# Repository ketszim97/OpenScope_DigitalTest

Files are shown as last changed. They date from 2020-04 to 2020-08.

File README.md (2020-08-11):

# OpenScope_DigitalTest
Digital Test board for an Open Source FPGA Oscilloscope

- Lattice MachX02 FPGA
- AD9481 250Msps ADC
- 128Mb Hyper RAM

Fusion Render 1
Fusion Render 2

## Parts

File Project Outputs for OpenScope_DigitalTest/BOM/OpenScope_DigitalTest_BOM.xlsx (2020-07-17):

Comment | Description | Designator | Footprint | LibRef | Quantity | Value | MANF | MFN_PN | Supplier 1 | Supplier Part Number 1 | Supplier 2 | Supplier Part Number 2 | LCSC Part Number
C0603 1uF 25V X7R | CAP CER 1UF 25V X7R 0603 | C3, C4 | C0603-IPC | C0603 1uF 25V X7R | 2 | 1uF | TDK |  | Digi-Key | 445-173615-1-ND |  |  | CL10A105KA8NNNC (https://lcsc.com/product-detail/Multilayer-Ceramic-Capacitors-MLCC-SMD-SMT_SAMSUNG_CL10A105KA8NNNC_1uF-105-10-25V_C5673.html)
C0603 100nF 25V X7R | Chip Capacitor, 0603, 100nF, 25V, X7R | C5, C6, C8, C9, C10, C11, C13, C14, C17, C19, C21, C27, C28, C29, C30, C31, C32, C33, C34, C35, C38, C41, C43, C44, C45, C46, C47, C48, C50, C52, C53, C54, C55, C58 | C0603-HIGH-DENSITY | C0603 100nF 25V X7R | 34 | 100nF | Murata |  | Digi-Key | 490-1524-1-ND |  |  | GRM188F51E104ZA01D (https://lcsc.com/product-detail/Multilayer-Ceramic-Capacitors-MLCC-SMD-SMT_muRata_GRM188F51E104ZA01D_100nF-104-80-20-25V_C86002.html)
GRM155R71H104KE14D | Chip Capacitor, 0402, 0.10uF, 50V, X7R | C7, C15, C18, C22, C23, C37, C39 | C0402-HIGH-DENSITY | C0402 0.1uF 50V X7R | 7 | 0.1uF | Murata |  | Digi-Key | 490-10700-1-ND |  |  | CC0402KRX7R8BB104 (https://lcsc.com/product-detail/Multilayer-Ceramic-Capacitors-MLCC-SMD-SMT_100nF-104-10-25V_C105883.html)
C0603 10uF 10V X5R | Chip Capacitor, 0603, 10uF, 10V, X5R | C1, C2, C12, C20, C24, C25, C26, C36, C51 | C0603-HIGH-DENSITY | C0603 10uF 10V X5R | 9 | 10uF | Murata |  | Digi-Key | 490-10474-1-ND |  |  | GRM188R61A106ME69D (https://lcsc.com/product-detail/Multilayer-Ceramic-Capacitors-MLCC-SMD-SMT_Murata-Electronics_GRM188R61A106ME69D_Murata-Electronics-GRM188R61A106ME69D_C90053.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)
C0402 10uF 10V | Chip Capacitor, 0402, 10uF, 10V, X5R | C16, C40 | C0402-HIGH-DENSITY | C0402 10uF 10V | 2 | 10uF | Samsung |  | Digi-Key | 1276-1450-2-ND |  |  | GRM155R61A106ME44D (https://lcsc.com/product-detail/Multilayer-Ceramic-Capacitors-MLCC-SMD-SMT_muRata_GRM155R61A106ME44D_10uF-106-20-10V_C77000.html)
C0603 4.7uF 6.3V X5R | Chip Capacitor, 0603, 4.7uF, 10V, X5R | C42, C49 | C0603-HIGH-DENSITY | C0402 4.7uF 6.3V X5R | 2 | 4.7uF | Samsung |  | Digi-Key | 1276-1907-1-ND |  |  | CL05A475MQ5NRNC (https://lcsc.com/product-detail/Others_Samsung-Electro-Mechanics_CL05A475MQ5NRNC_Samsung-Electro-Mechanics-CL05A475MQ5NRNC_C307423.html)
C0603 18pF 50V C0G_1 | Chip Capacitor, 0603, 18pF, 25V, C0G | C56, C57 | C0603-HIGH-DENSITY | C0402 18pF 50V C0G_1 | 2 | 18pF | KEMET |  | Digi-Key | 399-9019-1-ND |  |  | 0402CG180G500NT (https://lcsc.com/product-detail/Multilayer-Ceramic-Capacitors-MLCC-SMD-SMT_FH-Guangdong-Fenghua-Advanced-Tech-0402CG180G500NT_C182481.html)
LED0, LED1, LED2, LED3, LED4, LED5, LED6, LED7 | LED GREEN CLEAR 0603 SMD | D1, D2, D3, D4, D5, D6, D7, D8 | LED0603-IPC | LED 0603 Green | 8 | Green | Wurth Electronics |  | Digi-Key | 732-4971-1-ND |  |  | LTST-C193KGKT-5A (https://lcsc.com/product-detail/Light-Emitting-Diodes-LED_SMD-green_C125102.html)
5V, 3.3V PWR, 1.8V | LED RED CLEAR 0603 SMD | D9, D10, D11 | LED0603-IPC | LED 0603 Red | 3 | Red | Wurth Electronics |  | Digi-Key | 732-4979-1-ND |  |  | LTST-C193KRKT-5A (https://lcsc.com/product-detail/Light-Emitting-Diodes-LED_SMD-red_C157741.html)
VIN-, VIN+ | SMA Connector | J6, J7 | SMA_CONN | SMA | 2 |  | TE Connectivity |  | Digi-Key | A97594-ND |  |  | KH-SMA-K513-G (https://lcsc.com/product-detail/RF-Connectors-Coaxial-Connectors_Shenzhen-Kinghelm-Elec-KH-SMA-K513-G_C411575.html)
Ferrite Bead | 600 Ohms @ 100MHz 1 Ferrite Bead 0603 (1608 Metric) 500mA 380mOhm | L1, L2, L3 | L0603 | FB 0603 600R @ 100MHz | 3 | 600R 100MHz | Murata |  | Digi-Key | 490-1014-1-ND |  |  | CBG160808U601T (https://lcsc.com/product-detail/Ferrite-Beads_FH-Guangdong-Fenghua-Advanced-Tech-CBG160808U601T_C73326.html)
R0402 100R 1% | Chip Resistor, 0402, 100 ohms, 1%, 1/16 W | R1 | R0402-HIGH-DENSITY | R0402 100R 1% | 1 | 100 | Yageo |  | Digi-Key | 311-100LRCT-ND |  |  | ARG03DTC1000 (https://lcsc.com/product-detail/Others_Viking-Tech-ARG03DTC1000_C311907.html)
R0603 1K 1% | RES SMD 1K OHM 1% 1/10W 0603 | R2, R3, R4, R5, R6, R7, R8, R9 | R0603-IPC | R0603 1K 1% | 8 | 1k | Stackpole Electronics |  | Digi-Key | RMCF0603FG1K00CT-ND |  |  | 0603WAF1001T5E (https://lcsc.com/product-detail/Chip-Resistor-Surface-Mount_UNI-ROYAL-Uniroyal-Elec-0603WAF1001T5E_C21190.html)
R0603 4.99K 0.1% | RES SMD 4.99KOHM 0.1% 1/10W 0603 | R10, R11, R12 | R0603-HIGH-DENSITY | R0603 4.99K 0.1% | 3 | 4.99k | Panasonic |  | Digi-Key | P4.99KDBCT-ND |  |  | WR06X4991FTL (https://lcsc.com/product-detail/Chip-Resistor-Surface-Mount_Walsin-Tech-Corp-WR06X4991FTL_C163916.html)
R0603 2.2K 1% | RES SMD 2.2K OHM 1% 1/10W 0603 | R13, R14, R19 | R0603-IPC | R0603 2.2K 1% | 3 | 2.2k | Stackpole Electronics |  | Digi-Key | RMCF0603FT2K20CT-ND |  |  | 0603WAF2201T5E (https://lcsc.com/product-detail/Chip-Resistor-Surface-Mount_UNI-ROYAL-Uniroyal-Elec-0603WAF2201T5E_C4190.html)
R0603 12k 1% | RES 12K OHM 1% 1/10W 0603 | R15 | R0603-HIGH-DENSITY | R0603 12k 1% | 1 | 12k | Vishay |  | Digi-Key | 541-12.0KHCT-ND |  |  | 0603WAF1202T5E (https://lcsc.com/product-detail/Chip-Resistor-Surface-Mount_UNI-ROYAL-Uniroyal-Elec-0603WAF1202T5E_C22790.html)
R0603 10K 1% | RES SMD 10K OHM 1% 1/10W 0603 | R16, R17, R18, R23, R24 | R0603-IPC | R0603 10K 1% | 5 | 10k | Stackpole Electronics |  | Digi-Key | RMCF0603FT10K0CT-ND |  |  | MCT06030C1002FP500 (https://lcsc.com/product-detail/Others_Vishay-Intertech_MCT06030C1002FP500_Vishay-Intertech-MCT06030C1002FP500_C161803.html)
R0603 100 1% | RES SMD 100 OHM 1% 1/4W 0603 | R20, R21 | R0603-IPC | R0603 100 1% | 2 | 100 | Vishay Dale |  | Digi-Key | 541-3244-1-ND |  |  | WR06X101JTL (https://lcsc.com/product-detail/Chip-Resistor-Surface-Mount_Walsin-Tech-Corp-WR06X101JTL_C163845.html)
FPGA_PROGRAM_N, SW1, SW2 | SWITCH TACTILE SPST-NO 0.05A 12V | S1, S2, S3 | TL3342F260QG | SWITCH TACTILE SPST | 3 |  | E-Switch | TL3342F260QG | Digi-Key | EG5470CT-ND |  |  | TS5215A 160gf (https://lcsc.com/product-detail/Tactile-Switches_SHOU-HAN-TS5215A-160gf_C412369.html)
LD1086D2M33TR | 1.5A, Low Drop Positive Voltage Regulator, 3.3V, 4-Pin D2PAK/A, Tape and Reel | U1 | D2PAK_A_L | CMP-0244-00505-1 | 1 |  | STMicroelectronics | LD1086D2M33TR | Digi-Key | 497-1223-1-ND | Mouser | 511-LD1086D2M33-TR | C262918 (https://lcsc.com/product-detail/Others_STMicroelectronics_LD1086D2M33TR_STMicroelectronics-LD1086D2M33TR_C262918.html)
MCP1703T-1802E/CB | 250 mA, 16V, Low Quiescent Current LDO Regulator, 3-Pin SOT-23A, Extended Temperature, Tape and Reel | U2 | SOT-23A-CB3_N | CMP-0136-00766-1 | 1 |  | Microchip | MCP1703T-1802E/CB | Digi-Key | MCP1703T-1802E/CBCT-ND | Mouser | 579-MCP1703T-1802ECB
LCMXO2-4000 |  | U3 | TQFP144 | MachXO2-4000-TG144 | 1 |  | Lattice Semiconductor Corporation | LCMXO2-4000HC-4TG144C | DigiKey | 220-1460-ND | Mouser | 842-XO24000HC4TG144C
AD9481BSUZ-250 | Single ADC Pipelined 250Msps 8-bit Parallel/LVDS 44-Pin TQFP Tray | U4 | QFP80P1200X1200X120-44N | AD9481BSUZ-250 | 1 |  | Analog Devices Inc. | AD9481BSUZ-250 | DigiKey | AD9481BSUZ-250-ND | Mouser | 584-AD9481BSUZ-250
S70KS128 | PSRAM (Pseudo SRAM) Memory IC 128Mb (16M x 8) Parallel 166MHz 36ns 24-FBGA (6x8) | U5 | Cypress-VAA024 | S70KS | 1 |  | Cypress | S70KS1281DPBHV020 | Digi-Key | 2015-S70KS1281DPBHV020-ND | Mouser | 727-S70KS1281DPBHV02
FT2232HL-Reel | Dual High Speed USB To Multipurpose UART/FIFO IC, 64-pin LQFP, Tape and Reel | U6 | LQFP-64_M | CMP-0078-00023-3 | 1 |  | FTDI | FT2232HL-Reel | Digi-Key | 768-1024-1-ND | Mouser | 895-FT2232HL | C27882 (https://lcsc.com/product-detail/USB-ICs_FTDI-Future-Designs_FT2232HL-REEL_FTDI-Future-Designs-FT2232HL-REEL_C27882.html)
EEPROM 2Kb SPI | EEPROM Memory IC 2Kb (256 x 8, 128 x 16) SPI 3MHz 8-SOIC | U8 | SOIC127P600X175-8N | 93LC56C-I/SN | 1 |  | Microchip | 93LC56C-I/SN | Digi-Key | 93LC56C-I/SN-ND | Mouser | 579-93LC56C-I/SN
USB micro-B | CONN RCPT USB TYPE B 3A | USB1 | USB-MicroB | USB micro-B | 1 |  | Amphenol ICC | 629105150521 | Digi-Key | 609-4616-1-ND |  |  | C40955 (https://lcsc.com/product-detail/USB-Connectors_Jing-Extension-of-the-Electronic-Co-Jing-Extension-of-the-Electronic-Co-micro-5PBoard5-9No-column-plus-welding-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)
ABM8G-12.000MHZ-18-D2Y-T | Ultra Miniature Ceramic Glass Sealed SMD Cryastal, 12 MHz, 18 pF, +/- 20 ppm, -40 to 85 degC, 4-Pin SMD, RoHS, Tape and Reel |  | ABRACON_ABM8G_V | CMP-2000-05039-1 | 1 |  | Abracon | ABM8G-12.000MHZ-18-D2Y-T | Digi-Key | 535-10261-1-ND | Mouser | 815-ABM8G-12-18D2Y | C276421 (https://lcsc.com/product-detail/SMD-Crystal-Resonators_Abracon-LLC_ABM8G-12-000MHZ-B4Y-T_Abracon-LLC-ABM8G-12-000MHZ-B4Y-T_C276421.html)
EPSON 250MHz XTAL | 250MHz XO (Standard) LVDS Oscillator 2.5V ~ 3.3V Enable/Disable 6-SMD, No Lead | Y1 | EPSON SG5032 | SG5032VAN 250.000000M-KEGA3 | 1 |  | Epson | SG5032VAN 250.000000M-KEGA3 | Digi-Key | SER3984CT-ND | Mouser | 732-5032V250.00KEGA3
Renesas 125MHz OSC | 125MHz XO (Standard) HCMOS Oscillator 3.3V Enable/Disable 6-SMD, No Lead | Y2 | EPSON SG5032 | XLH535125.000000I | 1 |  | Renesas Electronics America Inc | XLH535125.000000I | Digi-Key | 800-4278-ND | Mouser | 972-LH535125.000000I

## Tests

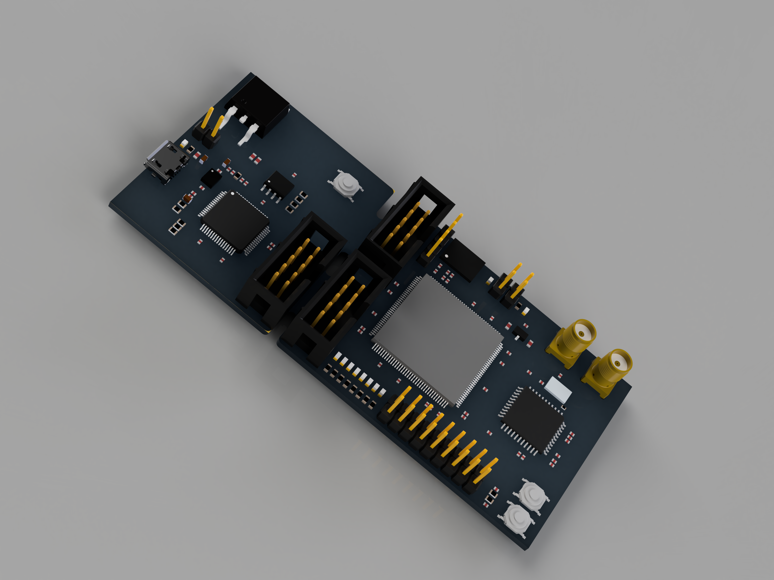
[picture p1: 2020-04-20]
Renders/DigitalTest_2020-Apr-18_06-35-39AM-000_CustomizedView22976808904_png.png

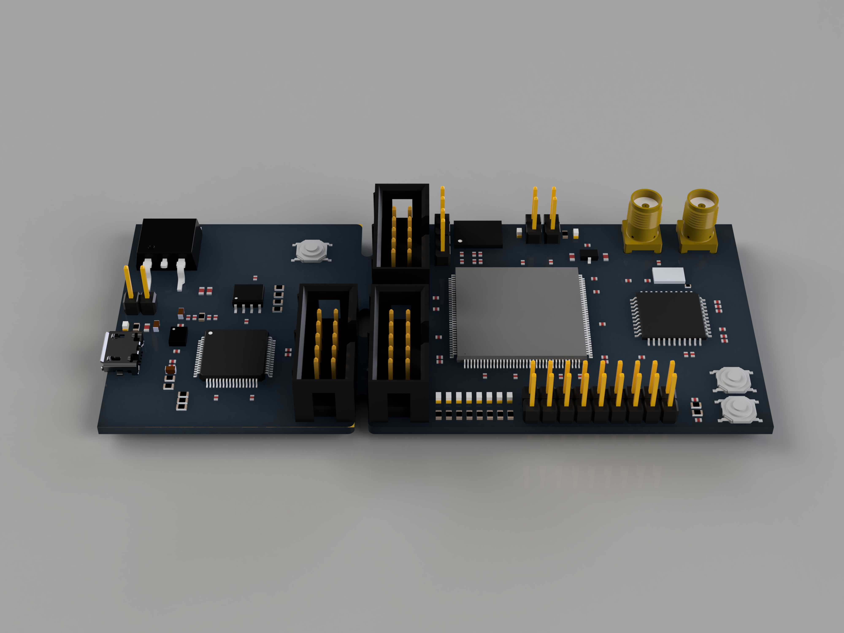
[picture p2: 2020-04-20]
Renders/DigitalTest_2020-Apr-18_06-37-25AM-000_CustomizedView3750263614_png.png

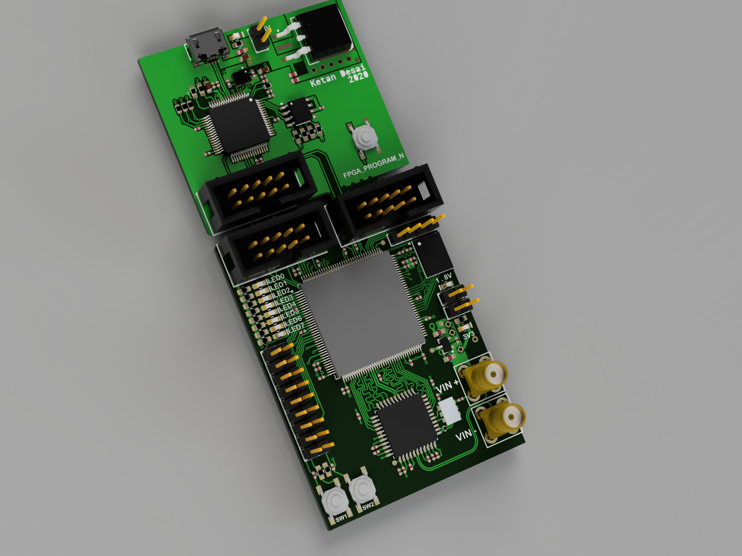
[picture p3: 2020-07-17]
Renders/DigitalTest_2020-Jul-16_10-25-01PM-000_CustomizedView61953568958_png.png

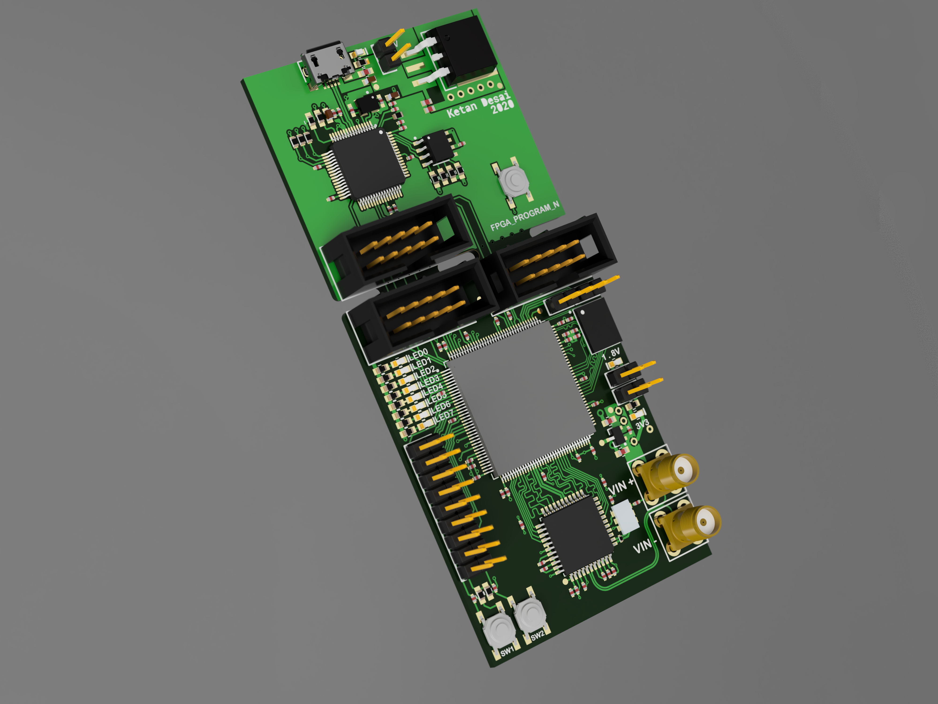
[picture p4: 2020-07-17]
Renders/DigitalTest_2020-Jul-16_10-29-32PM-000_CustomizedView10200404332_png.png

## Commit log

2020-03-11 Add Altium Project files. Gitignore component_libraries
    [DigitalTest.PcbDoc, DigitalTest_Top.SchDoc, OpenScope_DigitalTest.PrjPcb]
2020-03-11 Added hierarchical schematics. Placed FPGA symbol
    [DigitalTest_ADC.SchDoc, DigitalTest_FPGA.SchDoc, DigitalTest_Power.SchDoc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]
2020-03-12 Connected FPGA power and added FPGA decoupling
    [DigitalTest_Power.SchDoc]
2020-03-13 Completed FPGA power. Added LDOs
    [DigitalTest_Power.SchDoc]
2020-03-13 Added FPGA JTAG connections
    [DigitalTest_FPGA.SchDoc]
2020-03-17 Board outline defined. Layout FPGA decoupling caps
    [DigitalTest.PcbDoc, DigitalTest_FPGA.SchDoc, DigitalTest_Power.SchDoc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]
2020-04-06 Added ADC and ADC decoupling
    [DigitalTest_ADC.SchDoc]
2020-04-06 Added ADC connection to FPGA, add 250MHz CLK
    [DigitalTest_ADC.SchDoc, DigitalTest_FPGA.SchDoc, DigitalTest_Top.SchDoc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]
2020-04-06 Added Project logs to gitignore. Track Harness
2020-04-12 Added: - JTAG programmer - Memory
    [DigitalTest.PcbDoc, DigitalTest_ADC.SchDoc, DigitalTest_FPGA.SchDoc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]
2020-04-12 Added SMA conn, added spare IO, annotate
    [DigitalTest.PcbDoc, DigitalTest_ADC.SchDoc, DigitalTest_FPGA.SchDoc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]
2020-04-12 Fixed component sizes. Begin JTAG routing
    [DigitalTest_JTAG.SchDoc, OpenScope_DigitalTest.PrjPcb]
2020-04-12 Updated 3D models to more accurate ones
    [DigitalTest_JTAG.SchDoc, OpenScope_DigitalTest.PrjPcb]
2020-04-13 Initial parts placement. Fixed net classes
    [DigitalTest_ADC.SchDoc, DigitalTest_FPGA.SchDoc, DigitalTest_JTAG.SchDoc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]
2020-04-15 Completed most of layout. Swapped a few pins
    [DigitalTest_ADC.SchDoc, DigitalTest_FPGA.SchDoc, DigitalTest_JTAG.SchDoc]
2020-04-16 Initial Memory route and length match Swapped some pins
    [DigitalTest_FPGA.SchDoc, DigitalTest_Memory.SchDoc]
2020-04-18 Finished routing. Added parasolid file
    [DigitalTest_FPGA.SchDoc, DigitalTest_Memory.SchDoc]
2020-04-20 Added silkscreen. Added renders of final board
    [OpenScope_DigitalTest.PrjPcb]
2020-04-21 Added GERBERS, Changed most 0402 to 0603
    [DigitalTest_ADC.SchDoc, DigitalTest_FPGA.SchDoc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]
2020-04-23 Added BOM. Added 125Mhz XTAL (No ADC variant). Updated Gerbers
    [DigitalTest_ADC.SchDoc, DigitalTest_FPGA.SchDoc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]
2020-04-27 Added LCSC Part numbers for parts ordered
    [OpenScope_DigitalTest_BOM.xlsx]
2020-05-17 Added fixed gerbers. Added croissant.
    [OpenScope_DigitalTest.PrjPcb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]
2020-07-17 Add more renders
    [OpenScope_DigitalTest_BOM.xlsx]
2020-08-11 Add renders with IC print
